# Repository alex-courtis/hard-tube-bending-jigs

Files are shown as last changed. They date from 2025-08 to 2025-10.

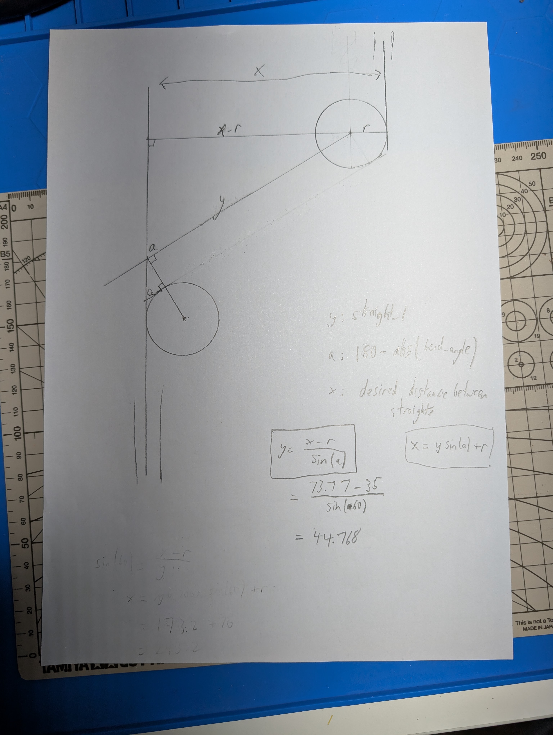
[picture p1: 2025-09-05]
parallel_calc.jpg

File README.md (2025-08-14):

# hard-tube-bending-jigs

## Printing

1. No infill: the walls are small and the tube groove must be smooth
2. Concentric top surface pattern: smooth bending surface
3. ABS or similar high temperature: avoid sticking to the tube

## Single Bends

Generate `.stl` with [openscad](https://openscad.org) or similar:

1. Set parameters in `single.scad`
2. Set `top = false`
3. Generate `bottom.stl`
4. Set `top = true`
5. Generate `top.stl`

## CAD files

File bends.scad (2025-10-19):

// outer
tube_radius = 8; // [4:1:10]

// to tube centre
bend_radius = 35; // [10:0.01:100]

// n bends, n+1 straights
bends = 3; // [1:1:3]

// of tube, left to right
bend_angle = [60, 120, 90]; // [0:1:180]

// 1: convex 0: concave
bend_convex = [1, 0, 1]; // [0:1:1]

// distance between centres of bends, left to right, 0 for no bend
straight_l = [80, 70, 90, 100]; // [0:0.001:1000]

// skirt, top and sides thickness, lip radii
wall_width = 1.6; // [0:0.1:5]

// of tube radius in addition to bend_radius
skirt_radius_multiplier = 2; // [1:0.1:3]

// extra bolt hole in bend, space allowing
bend_bolt = false;

// font size
text_height = 7; // [3:0.1:50]

// part separation
bottom_z = 100; // [0:1:500]

/* [Hidden] */

// default M3
bolt_diameter = 3; // [2:0.1:10]

// bolt hole size multiplier
bolt_radius_multiplier = 1.02; // [0:0.01:2]

// optional bolt head inset
bolt_inset_diameter = 6; // [0:0.1:10]

// optional bolt head inset
bolt_inset_depth = 2.5; // [0:0.1:10]

// default M3
nut_width = 5.5; // [1:0.1:10]

// nut hole width multiplier
nut_inset_multiplier = 1.03; // [1:0.01:2]

// nut depth, default M3
nut_depth = 4.5; // [0:0.1:20]

// above channel, applied to wall width
flange_height_multiplier = 0.6; // [0:0.1:1]

// applied to wall width
flange_width_multiplier = 1; // [0:0.1:5]

// inset
text_depth = 0.6; // [0:0.1:10]

// all
font = "Hack Nerd Font Mono";

// text length cutoff
min_text_straight_l = 25;

// global
$fn = 200; // [0:1:1000]

// derived
font_metrics = fontmetrics(font=font, size=text_height);

skirt_radius = bend_radius + tube_radius * skirt_radius_multiplier;
bolt_hole_diameter = bolt_diameter * bolt_radius_multiplier;
nut_inset_diameter = nut_width * nut_inset_multiplier * 2 / sqrt(3);

channel_width = bend_radius - tube_radius - 2 * wall_width;
channel_height = tube_radius - wall_width;

total_width_top = bend_radius + wall_width;
total_width_bottom = skirt_radius + wall_width;
total_width_bottom_no_skirt = bend_radius + wall_width;
total_height = tube_radius + wall_width;

echo(font_metrics=font_metrics);

echo(skirt_radius=skirt_radius);
echo(bolt_hole_diameter=bolt_hole_diameter);
echo(bolt_inset_diameter=bolt_inset_diameter);
echo(nut_inset_diameter=nut_inset_diameter);

echo(channel_width=channel_width);
echo(channel_height=channel_height);

echo(total_width_top=total_width_top);
echo(total_width_bottom=total_width_bottom);
echo(total_height=total_height);

assert(total_width_top == total_width_bottom_no_skirt);

function truncv(v, l) = [for (i = [0:l - 1]) v[i]];

module cross_section_bottom() {

  // bottom skirt
  square([skirt_radius, wall_width], center=false);

  // bottom lip
  translate(v=[skirt_radius, 0, 0])
    intersection() {
      square([wall_width, wall_width], center=false);

      circle(r=wall_width);
    }

  // body
  difference() {
    square([bend_radius, total_height], center=false);

    // hollow
    translate(v=[wall_width, wall_width, 0])
      square([channel_width, channel_height + wall_width], center=false);

    // tube hollow
    translate(v=[bend_radius, total_height, 0])
      circle(r=tube_radius);
  }
}

module cross_section_top() {

  // top lip
  translate(v=[bend_radius, 0, 0])
    intersection() {
      square([wall_width, wall_width], center=false);
      circle(r=wall_width);
    }

  difference() {

    // outer
    square([bend_radius, total_height], center=false);

    // channel
    translate(v=[wall_width, wall_width, 0])
      square([channel_width, channel_height + wall_width], center=false);

    // tube hollow
    translate(v=[bend_radius, total_height, 0])
      circle(r=tube_radius);
  }
}

module cross_section_brace(flange_inner, flange_outer) {
  translate(v=[wall_width, wall_width, 0]) {
    square([channel_width, channel_height], center=false);

    y = wall_width * flange_width_multiplier;
    z = channel_height + wall_width * (1 + flange_height_multiplier);

    if (flange_inner)
      square([y, z], center=false);

    if (flange_outer)
      translate(v=[channel_width - y, 0])
        square([y, z], center=false);
  }
}

module bolt_hole(top) {

  // hole
  color(c="black")
    cylinder(h=total_height, d=bolt_hole_diameter, center=false);

  if (top) {
    // bolt sink
    color(c="brown")
      cylinder(h=bolt_inset_depth, d=bolt_inset_diameter, center=false);
  } else {
    // captive nut
    color(c="tan")
      cylinder(h=nut_depth, d=nut_inset_diameter, center=false, $fn=6);
  }
}

module extrude_text(text, dx, dy, halign) {

  linear_extrude(height=text_depth, center=false)
    // shift up from baseline valign
    translate(v=[dx, dy - font_metrics.max.descent, 0])
      text(font=font, size=text_height, text=text, valign="baseline", halign=halign);
}

module extrude_straight(l, al, ar, top, text) {

  brace_y = max(bolt_inset_diameter, nut_inset_diameter) + wall_width;

  brace1 = (brace_y < l);
  brace2 = (brace_y * 2 < l);

  brace_hole_dy = ( -l + brace_y) / 2;

  difference() {

    union() {

      rotate(a=90, v=[1, 0, 0]) {

        // body
        color(c="gray")
          linear_extrude(height=l, center=true) {
            if (top)
              cross_section_top();
            else
              cross_section_bottom();
          }

        // brace
        if (brace1) {
          color(c="darkblue")
            translate(v=[0, 0, -brace_hole_dy])
              linear_extrude(height=brace_y, center=true)
                cross_section_brace(flange_inner=top, flange_outer=top);
        }

        // brace
        if (brace2) {
          color(c="cadetblue")
            translate(v=[0, 0, brace_hole_dy])
              linear_extrude(height=brace_y, center=true)
                cross_section_brace(flange_inner=top, flange_outer=top);
        }
      }
    }

    // bend info
    if (top && l >= min_text_straight_l) {
      mirror(v=[0, 1, 0]) {
        rotate(a=270, v=[0, 0, 1]) {
          dy = bend_radius + wall_width - wall_width * 2 - font_metrics.nominal.ascent;

          extrude_text(
            text=is_num(al) ? str(al, "°") : str("R", bend_radius, " ø", tube_radius * 2),
            dx=-l / 2 + (is_num(al) ? 0 : wall_width),
            dy=dy,
            halign="left"
          );

          extrude_text(
            text=is_num(ar) ? str(ar, "°") : str("ø", tube_radius * 2, " R", bend_radius),
            dx=l / 2 - (is_num(ar) ? 0 : wall_width),
            dy=dy,
            halign="right"
          );

          // this only works for a=120
          if (is_num(al) && is_num(ar) && al == ar && al == 120) {
            parallel_straights_distance = l * sin(180 - al) + bend_radius;
            echo(parallel_straights_distance=parallel_straights_distance);
            echo("l * sin(a) + bend_radius");
            extrude_text(
              text=str("P", round(parallel_straights_distance * 1000) / 1000),
              dx=0,
              dy=wall_width + font_metrics.interline + wall_width,
              halign="center"
            );
          }

          extrude_text(
            text=str("L", l),
            dx=0,
            dy=wall_width,
            halign="center"
          );
        }
      }
    }

    // bolt holes
    if (brace1)
      translate(v=[wall_width + channel_width / 2, brace_hole_dy, 0])
        bolt_hole(top=top);

    if (brace2)
      translate(v=[wall_width + channel_width / 2, -brace_hole_dy, 0])
        bolt_hole(top=top);
  }
}

module extrude_bend(a, c, top) {

  // mirrored rotation for negative angles
  mx = c ? 0 : 1;
  dx = c ? 0 : -bend_radius * 2;
  bolt_dx = dx + channel_width / 2 + wall_width;

  mirror(v=[mx, 0])
    translate(v=[dx, 0])
      difference() {

        // body
        color(c="slategray")
          rotate_extrude(angle=180 - a)
            mirror(v=[mx, 0])
              translate(v=[dx, 0]) {
                if (top)
                  cross_section_top();
                else
                  cross_section_bottom();

                cross_section_brace(flange_inner=top, flange_outer=top);
              }

        // bolt hole
        if (bend_bolt)
          rotate(a=(180 - a) / 2)
            mirror(v=[mx, 0])
              translate(v=[bolt_dx, 0, 0])
                bolt_hole(top=top);
      }
}

module build(
  n = bends,
  ls = truncv(straight_l, bends + 1),
  as = truncv(bend_angle, bends),
  cs = truncv(bend_convex, bends),
  top = false
) {

  l = ls[n];
  a = as[n];
  c = cs[n];
  a_next = bend_angle[n - 1];

  dx = is_num(a) && c ? 0 : bend_radius * 2;
  rot = is_num(a) ? 180 + c * 2 * a - a : 0;

  // rotate fulcrum about origin
  translate(v=[dx, 0, 0])
    rotate(a=rot)
      translate(v=[-dx, 0, 0]) {

        // straight shift y to origin
        translate(v=[0, -l / 2, 0])
          extrude_straight(l=l, al=a_next, ar=a, top=top);

        // bends in place at origin
        if (is_num(a))
          extrude_bend(a=a, c=c, top=top);
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

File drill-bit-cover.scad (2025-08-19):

d_entry = 10.9; // [1:0.01:50]
h_entry = 5; // [1:0.01:50]

d_tube = 11.9; // [1:0.01:50]
h_tube = 20; // [1:0.1:50]

d_bearing = 11.10; // [1:0.01:50]
h_bearing = 5.5; // [1:0.01:50]

d_nut = 8.6; // [1:0.01:50]
h_nut = 7; // [1:0.01:50]

$fn = 400;

// tube
render() {
  difference() {
    color(c="purple")
      cylinder(d=d_tube, h=h_tube);
    color(c="blue")
      cylinder(d=d_bearing, h=h_bearing);
    color(c="red")
      cylinder(d=d_nut, h=h_nut + h_bearing);
  }
  color(c="green")
    translate(v=[0, 0, h_tube])
      cylinder(d1=d_tube, d2=d_entry, h=h_entry);
}

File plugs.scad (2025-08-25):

h_flange = 3.0; // [0:0.01:50]

d_rod_outer = 3.75; // [0:0.001:50]
d_rod_inner = 3.90; // [0:0.001:50]

d_tube = 11.85; // [1:0.01:50]
h_tube = 15; // [1:0.1:50]

d1_flange_tube = 23; // [0:0.01:50]
d2_flange_tube = 20; // [0:0.01:50]

d_socket = 11.4; // [1:0.01:50]
h_socket = 6.2; // [1:0.1:50]

d1_flange_socket = 23; // [0:0.01:50]
d2_flange_socket = 20; // [0:0.01:50]

$fn = 400;

// tube with female rod
color(c="blue") {
  translate(v=[0, -d1_flange_tube, 0]) {
    difference() {
      union() {
        translate(v=[0, 0, h_flange])
          cylinder(d=d_tube, h=h_tube);
        cylinder(d1=d1_flange_tube, d2=d2_flange_tube, h=h_flange);
      }
      #cylinder(d=d_rod_inner, h=h_tube + h_flange);
    }
  }
}

// tube with male rod
color(c="orange") {
  translate(v=[0, d_tube, 0]) {
    cylinder(d=d_tube, h=h_tube);
    translate(v=[0, 0, h_tube + h_flange])
      mirror(v=[0, 0, 1])
        cylinder(d1=d1_flange_tube, d2=d2_flange_tube, h=h_flange);
    cylinder(d=d_rod_outer, h=h_tube + h_flange * 2 + h_socket);
  }
}

// socket with female rod and flange
translate(v=[d1_flange_socket, 0, 0]) {
  color(c="green") {
    difference() {
      union() {
        translate(v=[0, 0, h_flange])
          cylinder(d=d_socket, h=h_socket);
        cylinder(d1=d1_flange_socket, d2=d2_flange_socket, h=h_flange);
      }
      #cylinder(d=d_rod_inner, h=h_socket + h_flange);
    }
  }
}

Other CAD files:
u.scad

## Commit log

2025-06-27 POC u bend
    [u.poc.3mf, u.scad]
2025-06-28 split top and bottom, allow any angles
    [u.scad]
2025-06-28 add bolt holes
    [single.scad]
2025-06-28 add captive nuts
    [single.scad]
2025-06-28 add text
    [single.scad, single.top.t16a45r30.stl]
2025-06-28 single top prints
    [single.top.t16a45r30.3mf, single.top.t16a45r30.generic.3mf]
2025-06-28 hollow with solid bolt holes
    [single.bottom.t16a45r30.3mf, single.bottom.t16a45r30.generic.3mf, single.scad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]
2025-06-29 add assistive bend at end of straight
    [single.scad]
2025-06-30 slightly larger bolt and nut holes
    [single.scad]
2025-06-30 assistive bends wrap all the way around
    [single.scad]
2025-07-06 quarter circle lip on top and skirt
    [single.scad]
2025-07-06 nut holes are full width and offset, tidy
    [single.scad]
2025-07-07 wall width gap above bolt holes
    [single.scad]
2025-07-07 inset bolt head
    [single.scad]
2025-07-07 remove assistive bends to be replaced by guides
    [single.scad]
2025-07-07 use a single straight function, move bolts to either end of the straights
    [single.scad]
2025-08-12 remove 3mf
    [single.bottom.t16a45r30.3mf, single.bottom.t16a45r30.generic.3mf, single.bottom.t16a45r30.stl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]
2025-08-12 plugs: first try
    [plugs.scad]
2025-08-13 plugs: split into tube and socket with connector
    [plugs.scad]
2025-08-13 plugs: inner and outer connector diameters
    [plugs.scad]
2025-08-13 plugs: better defaults
    [plugs.scad]
2025-08-14 plugs: use a rod to connect
    [plugs.scad]
2025-08-14 plugs: add a male tube rod, tweak sizes
    [plugs.scad]
2025-08-14 plugs: tweak fitting
    [plugs.scad]
2025-08-14 single: 16-0-42.05-100
    [single.scad]
2025-08-15 single: 16-90-42.05-150
    [single.scad]
2025-08-15 single: adjust hole sizes, use enum for piece rather than boolean
    [single.scad]
2025-08-15 single: use a cylinder with brace for the shaft
    [single.scad]
2025-08-16 Revert "single: use a cylinder with brace for the shaft"
    This reverts commit 0c4e581471227d36deaa67e228b4f75ccaf4ea53.
    [single.scad]
2025-08-16 single: add flange to shaft
    [single.scad]
2025-08-16 single: smaller wall width, remove piece selection
    [single.scad]
2025-08-16 single: shafts are extruded and straights are symetrical
    [single.scad]
2025-08-16 single: bend shaft
    [single.scad]
2025-08-17 single: fix duplicate bend flange, widen shaft for nut hole, tidy variable names
    [single.scad]
2025-08-17 single: 3 braces, one at bend
    [single.scad]
2025-08-17 single: use text_size param, align for holes
    [single.scad]
2025-08-17 single: vertically centre text
    [single.scad]
2025-08-17 single: inset brace hole and reduce its width
    [single.scad]
2025-08-17 single: fix skirt multiplier, shorten text
    [single.scad]
2025-08-18 plugs: add flange to male rod
    [plugs.scad]
2025-08-18 extract lib
    [lib.scad, single.scad]
2025-08-18 rename for refactor
    [bends-single.scad]
2025-08-18 bends: split into part options
    [bends-single.scad, bends.scad]
2025-08-18 bends: multiple straight lengths printed on straight
    [bends-single.scad, bends.scad]
2025-08-19 add drill-bit-cover
    [drill-bit-cover.scad]
2025-08-19 bends: extract more common and parameterise
    [bends-lib.scad, bends-single.scad, bends.scad]
2025-08-19 bends: simplify text generation
    [bends-lib.scad, bends-single.scad, bends.scad]
2025-08-23 bends: braces at both ends of the straights
    [bends-lib.scad, bends-single.scad, bends.scad]
2025-08-24 single: optional radius bolt, tidy text
    [bends-lib.scad, bends-single.scad, bends.scad]
2025-08-24 double: extremely messy and fragile
    [bends-double.scad, bends-lib.scad, bends-single.scad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]
2025-08-25 plugs: thicker threads to match fittings
2025-08-25 plugs: shorter thread
    [plugs.scad]
2025-08-25 double: generify and fix bugs, some TODOs
    [bends-double.scad, bends-lib.scad, bends-single.scad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]
2025-09-03 bends: condense to one codepath, allow multiple bends
    [bends-double.scad, bends-lib.scad, bends-single.scad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]
2025-09-03 bends: allow 0 degree
    [bends.scad]
2025-09-03 bends: ensure bends set in all params
    [bends.scad]
2025-09-04 bends: line up negative bottom bends, tidy
    [bends.scad]
2025-09-04 bends: double_cpu_rad
    [bends.scad]
2025-09-04 bends: fix negative radii
    [bends.scad]
2025-09-04 bends: cpu rad length
    [bends.scad]
2025-09-05 bends: fix bolt hole for negative angles
    [bends.scad]
2025-09-05 bends: tidy params
    [bends.scad]
2025-09-05 bends: fix 0 degree angle text
    [bends.scad]
2025-09-05 bends: print distance between parallel straights
    [bends.scad]
2025-09-05 bends: single_cpu_rad, inset end text
    [bends.scad]
2025-10-08 bends: specify convexity
    [bends.scad]
2025-10-08 bends: only render straight bends/text if there's room
    [bends.scad]
2025-10-18 bends: double_gpu_rad
    [bends.scad]
2025-10-19 bends: single_gpu_rad_2
    [bends.scad]
2025-10-19 bends: add R and ø to both ends
    [bends.scad]
